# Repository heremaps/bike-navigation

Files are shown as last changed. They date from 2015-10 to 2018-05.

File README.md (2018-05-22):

# This repository has been archived!

The current version of the HERE WeGo app on Android does not support BLE devices anymore.

# BikeNavigation

The bike navigation project was born out of the HERE maker lab in Berlin. A group of employees volunteered their time to build a companion device that connects to the HERE app on Android, including an open-source toolkit to build a custom bike navigation device.

## License

Unless otherwise noted in `LICENSE` files for specific files or directories, the [LICENSE](LICENSE) in the root applies to all content in this repository.

## Directory Contents

* *arduino*: Codes implementing BikeNavigation BLE profile
* *ble_specs*: Documentation describing BikeNavigation BLE profile
* *board*: PCB Design files for BikeNavigation
* *enclosure*: 3d and acrylic cases for BikeNavigation

## Disclaimer

You are required to provide the end-user of the device with the following notice prior to use and are responsible to localize this notice according to local laws: “Focus on the traffic when using the device - your first consideration while using the device in traffic has to be safety.”

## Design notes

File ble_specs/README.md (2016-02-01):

# BikeNavigation

## BikeNavigation BLE Profile

BikeNavigation BLE profile enables GATT client to send turn-by-turn navigation instructions to BikeNavigation device.

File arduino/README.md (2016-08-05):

# BikeNavigation

## Arduino code

Runs BikeNavigation BLE profile and controls LED matrix display.

### Arduino source files

* *ble_display.ino*: Arduino sketch file. Contains code for the board initialization and main loop, including reading of incoming commands from Bluetooth controller and getting data from the compass.
* *icons.h*: Header file containing data structures and types needed for storing LED patterns for all the icons that can be shown on the LED matrix. C++ code for patterns can be generated by code generation script (see below).
* *compass.h*: Header file describing the class to be used to deal with compass.
* *compass.cpp*: Source file containing implementation of the Compass class.

### Code generation script

Python script `generate_icons_led_matrix_studio.py` can be used to convert the output of [LED Matrix Studio](http://maximumoctopus.com/electronics/builder.htm) to the C++ structures which can be used directly in code. Usage:

    ./generate_icons_led_matrix_studio.py filename varname

Where:

* *filename*: LED patterns file generated with [LED Matrix Studio](http://maximumoctopus.com/electronics/builder.htm)
* *varname*: name of variable where LED patterns will be stored in C++ code

Generated code should be added to `icons.h` file. Also command codes and function converting command code to the icon should be adapted to the new code.

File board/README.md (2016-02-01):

# BikeNavigation

## BikeNavigation PCB & schematic

The board and the schematic are designed with [CadSoft EAGLE](http://www.cadsoftusa.com/eagle-pcb-design-software/about-eagle/). To work with the files you need at least EAGLE version 6.

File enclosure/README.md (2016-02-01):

# BikeNavigation

## Enclosure

* OpenSCAD files for 3d printed case
* SVG file for acrylic case

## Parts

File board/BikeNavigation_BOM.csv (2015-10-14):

Qty | Value | Device | Package | Parts | Description | PARTNO | PROD_ID | TP_SIGNAL_NAME
49 |  | LEDCHIP-LED0603 | CHIP-LED0603 | LED1, LED2, LED3, LED4, LED5, LED6, LED7, LED8, LED9, LED10, LED11, LED12, LED13, LED14, LED15, LED16, LED17, LED18, LED19, LED20, LED21, LED22, LED23, LED24, LED25, LED26, LED27, LED28, LED29, LED30, LED31, LED32, LED33, LED34, LED35, LED36, LED37, LED38, LED39, LED40, LED41, LED42, LED44, LED45, LED46, LED47, LED48, LED49, LED50 | LED
7 |  | PNP-TRANSISTOR_SOT23 | SOT23 | Q1, Q2, Q3, Q4, Q5, Q6, Q7 | PNP TRANSISTOR
1 |  | SJ | SJ | SJ1 | SMD solder JUMPER
1 | 100K | R-EU_R0402 | R0402 | R5 | RESISTOR, European symbol
1 | 100K | R-EU_R0402 | R0402 | R15 | RESISTOR, European symbol | P100KJCT-ND
1 | 100K | R-EU_R0402 | R0402 | R9 | RESISTOR, European symbol | P510KJCT-ND
3 | 100n | C-EUC0402 | C0402 | C1, C5, C10 | CAPACITOR, European symbol | 445-3445-1-ND
1 | 10K | R-EU_R0402 | R0402 | R2 | RESISTOR, European symbol
1 | 10n | C-EUC0402 | C0402 | C11 | CAPACITOR, European symbol | 445-1260-1-ND
1 | 16Mhz | RESONATORSMD | RESONATOR-SMD | Y2 | Resonator | *
1 | 1K | R-EU_R0402 | R0402 | R1 | RESISTOR, European symbol
1 | 1u | CPOL-EUSMCA | SMC_A | C4 | POLARIZED CAPACITOR, European symbol
2 | 22 | R-EU_R0402 | R0402 | R12, R13 | RESISTOR, European symbol
2 | 220 | R-EU_R0402 | R0402 | R14, R16 | RESISTOR, European symbol
1 | 220n | C-EUC0402 | C0402 | C3 | CAPACITOR, European symbol | 445-3445-1-ND
1 | 2K | R-EU_R0402 | R0402 | R10 | RESISTOR, European symbol
2 | 330 | R-EU_R0402 | R0402 | R3, R4 | RESISTOR, European symbol
1 | 436331045822 | 436331045822 | 436331045822 | SW1 | WS-TUS-3.5x4.7 mm side push SMD Tact Switch with boss design, 4 pins
5 | 4u7 | CPOL-EUSMCA | SMC_A | C2, C7, C8, C9, C12 | POLARIZED CAPACITOR, European symbol
1 | ATMEGA32U4TQFP-44 | ATMEGA32U4TQFP-44 | TQFP44 | IC5 | Atmel 44-pin 8-bit Microcontroller with 32KBytes of ISP Flash and USB Controller
3 | FIDUCIAL | FIDUCIAL | FIDUCIAL_1MM | U$1, U$2, U$3 | For use by pick and place machines to calibrate the vision/machine, 1mm
1 | GRN | LEDCHIP-LED0603 | CHIP-LED0603 | RX | LED
1 | GRN | LEDSML0805 | SML0805 | LED51 | LED
1 | HM-11_HM-11 | HM-11_HM-11 | HM-11_HM-11 | HM11
1 | HMC5883LSMD | HMC5883LSMD | 16LPCC | IC1 | 3 Axis Digital Compass IC |  | IC-10284
1 | LTC2950CDDB-1 | LTC2950-1DFN(3X2) | DDB-8 | IC6 | LTC2950-1 Push button ON/OFF Controler LINEAR TECHNOLOGY | LTC2950IDDB-1#TRMPBFCT-ND
1 | MCP1824-3.3V (fixed) | V_REG_LDOSMD | SOT23-5 | U1 | Voltage Regulator LDO
1 | MCP73831 | MCP73831 | SOT23-5 | U2 | Miniature single cell, fully integrated Li-Ion, Li-polymer charge management controller |  | IC-09995
1 | MICRO-USB-SMD(ZX62-B-5PA) | MICRO-USB-SMD(ZX62-B-5PA) | MICRO-USB5+6P-SMD-0.65-AB | J1 | 320010005
8 | PTR1TP20SQ | PTR1TP20SQ | TP20SQ | BAT+, BAT-, TP_GND, TP_MISO, TP_MOSI, TP_RST, TP_SCK, TP_VCC | TEST PIN
1 | RED | LEDCHIP-LED0603 | CHIP-LED0603 | TX | LED
1 | RED | LEDSML0805 | SML0805 | LED43 | LED
1 | STP16CP05 | STP16CP05 | TSSOP24 | IC2

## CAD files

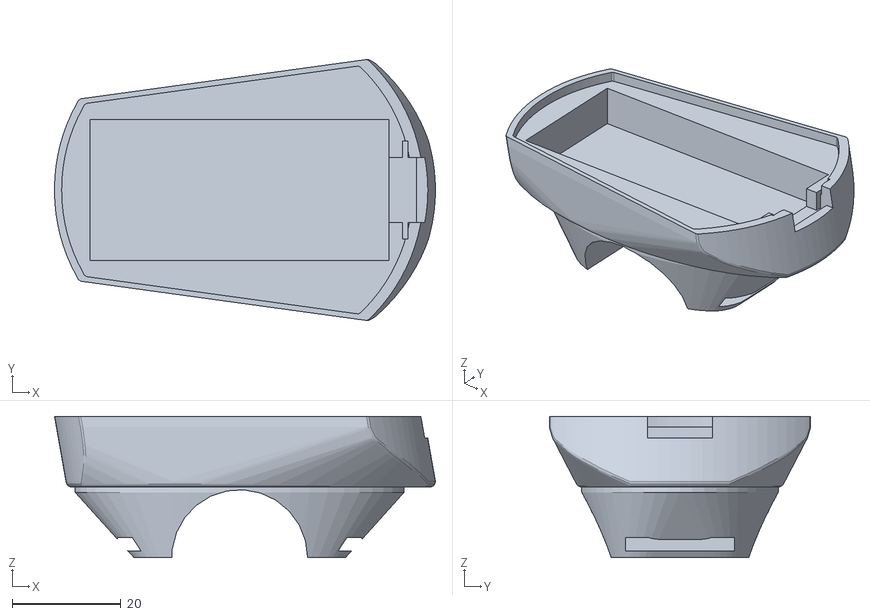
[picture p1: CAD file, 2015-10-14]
enclosure/openscad/case_B.stl
70.1 x 48.0 x 26.0

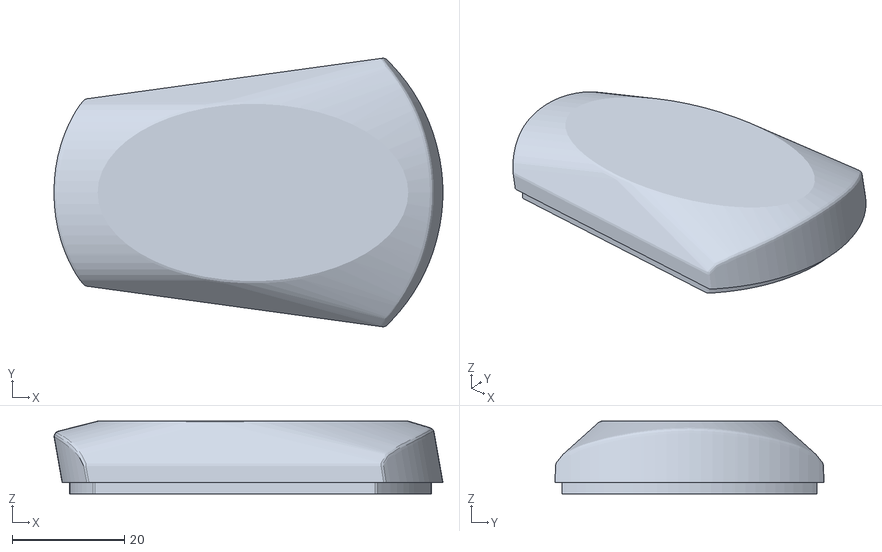
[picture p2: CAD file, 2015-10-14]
enclosure/openscad/case_A.stl
69.4 x 48.0 x 13.0

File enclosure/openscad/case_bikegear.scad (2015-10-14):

w=26;
l=55;
h=20;

module oval(w,h, height, center = false) {
 scale([1, h/w, 1]) cylinder(h=height, r=w, center=center,$fn=50);
}

module block(l,w,h){
union(){
	//display matrix 20x20x6, modify h-x to control height
	color("white")translate([20/2+11.5,0,3.2+(h-6)]) cube([20,20,6],center=true);
	//clearance pcb to display
	color("green")translate([l/2,0,(h-5)]) cube([l,w,2],center=true);
	//pcb and battery volume
	color("red") translate([l/2,0,(h-6)/2]) cube ([l,w,h-6], center=true);
}//union
}//block(l,w,h);

module body(){
intersection(){
hull(){
	oval(l*0.7,w*0.7,2,false);
	translate([0,0,10]) hull(){
		translate([-l/2,0,0])oval(l*0.5,w*0.6,5,false);
		translate([l/2,0,0]) cylinder(h=5,r=w/2*1.8, $fn=25);
	}
	translate([0,0,h]) oval(l*0.5,w*0.6,2,false);

}//hull

//make something more interesting with the front and back
rotate(a=-10,v=[0,1,0]) translate([2,0,-20]) cylinder(h=70,r=65/2,$fn=100);

}//intersect
}//translate([l/2,0,-3]) body();

module soften_body(shell=false){
difference(){
 minkowski(){
	sphere(1,$fs=0.5);
	translate([l/2,0,-2]) body();
}
	block(l,w,h);
//we empthy the mass, and leave just outer shell
if(shell==true) { translate([1,0,0.5]) scale(0.95) minkowski(){
	sphere(1,$fs=0.5);
	translate([l/2,0,-2]) body();
	}//mink
	}//if
	}//diff
}//soften_body(false);

//to test the cut seam
zcut=10;
//projection(cut=true) translate([0,0,-zcut]) soften_body(true);

//seam prep
module seam(){
difference(){
 translate([1,0,0.5]) scale(0.95) minkowski(){
	sphere(1,$fs=0.5);
	translate([l/2,0,-2]) body();
	}
 translate([1.6,0,0.5]) scale([0.92,0.9,0.9]) minkowski(){
	sphere(1,$fs=0.5);
	translate([l/2,0,-2]) body();
	}
}//diff
}


module seam_rib(){
translate([0,0,zcut-2]) 
	linear_extrude(height=2) 
		projection(cut=true) translate([0,0,-zcut]) seam();
}

 module seam_inner(){
 translate([0,0,zcut-2]) 
	linear_extrude(height=2) 
		projection(cut=true) translate([0,0,-zcut]) {  
    translate([1,0,0.5]) scale(0.95) minkowski(){
	sphere(1,$fs=0.5);
	translate([l/2,0,-2]) body();
	}
    }
 } // seam_inner();
    
//base, handlebar 25mm radius    
module basegrip(){
difference(){
hull(){
	translate([l/2,0,-3]) oval(l*0.55,w*0.7,2,false);
	translate([l/2,0,-15]) rotate(a=90,v=[1,0,0]) translate([0,0,-10]) cylinder(h=20,r=25/2+2,$fn=25);
}//hull
	translate([l/2,0,-25]) cube([40,40,20],center=true);
	handlebar();
	translate([l/2-25/2-5,0,-25/2]) cube([10,20,2.5],center=true);
	translate([l/2-25/2-3,0,-25/2-1.5]) rotate(a=60,v=[0,1,0]) cube([4,18,2.5],center=true);
	translate([l/2+25/2+5,0,-25/2]) cube([10,20,2.5],center=true);
	translate([l/2+25/2+3,0,-25/2-1.5]) rotate(a=60,v=[0,-1,0]) cube([4,18,2.5],center=true);

}//diff
}//basegrip();


module handlebar(){
	color("blue") translate([l/2,0,-15]) rotate(a=90,v=[1,0,0]) translate([0,0,-50]) cylinder(h=100,r=25/2,$fn=25);
}//handlebar();


module assy(){
union(){
	soften_body();
	translate([0,0,-1]) basegrip();
}
} //assy();


module cut_b(){ //bottom
union(){
	difference(){
		assy();
		translate([0,0,35]) cube([200,100,50],center=true);
		//%seam_rib();
        seam_inner();
		//switch space
		translate([l,0,8]) cube([24,12,4],center=true);
		translate([l,0,8]) cube([10,12,8],center=true);
		translate([l+3,0,8]) cube([1,18,8],center=true);
	}//diff
	
}//union
} 
//translate([0,0,-20])
//cut_b();

module cut_a(){ //top
union(){
    difference(){
            assy();
            //cut_b();
            translate([0,0,-15]) cube([200,100,50],center=true);
            //translate([l,0,5]) cube([12,12,8],center=true);
    }
    seam_rib();
    }//union 
} cut_a();

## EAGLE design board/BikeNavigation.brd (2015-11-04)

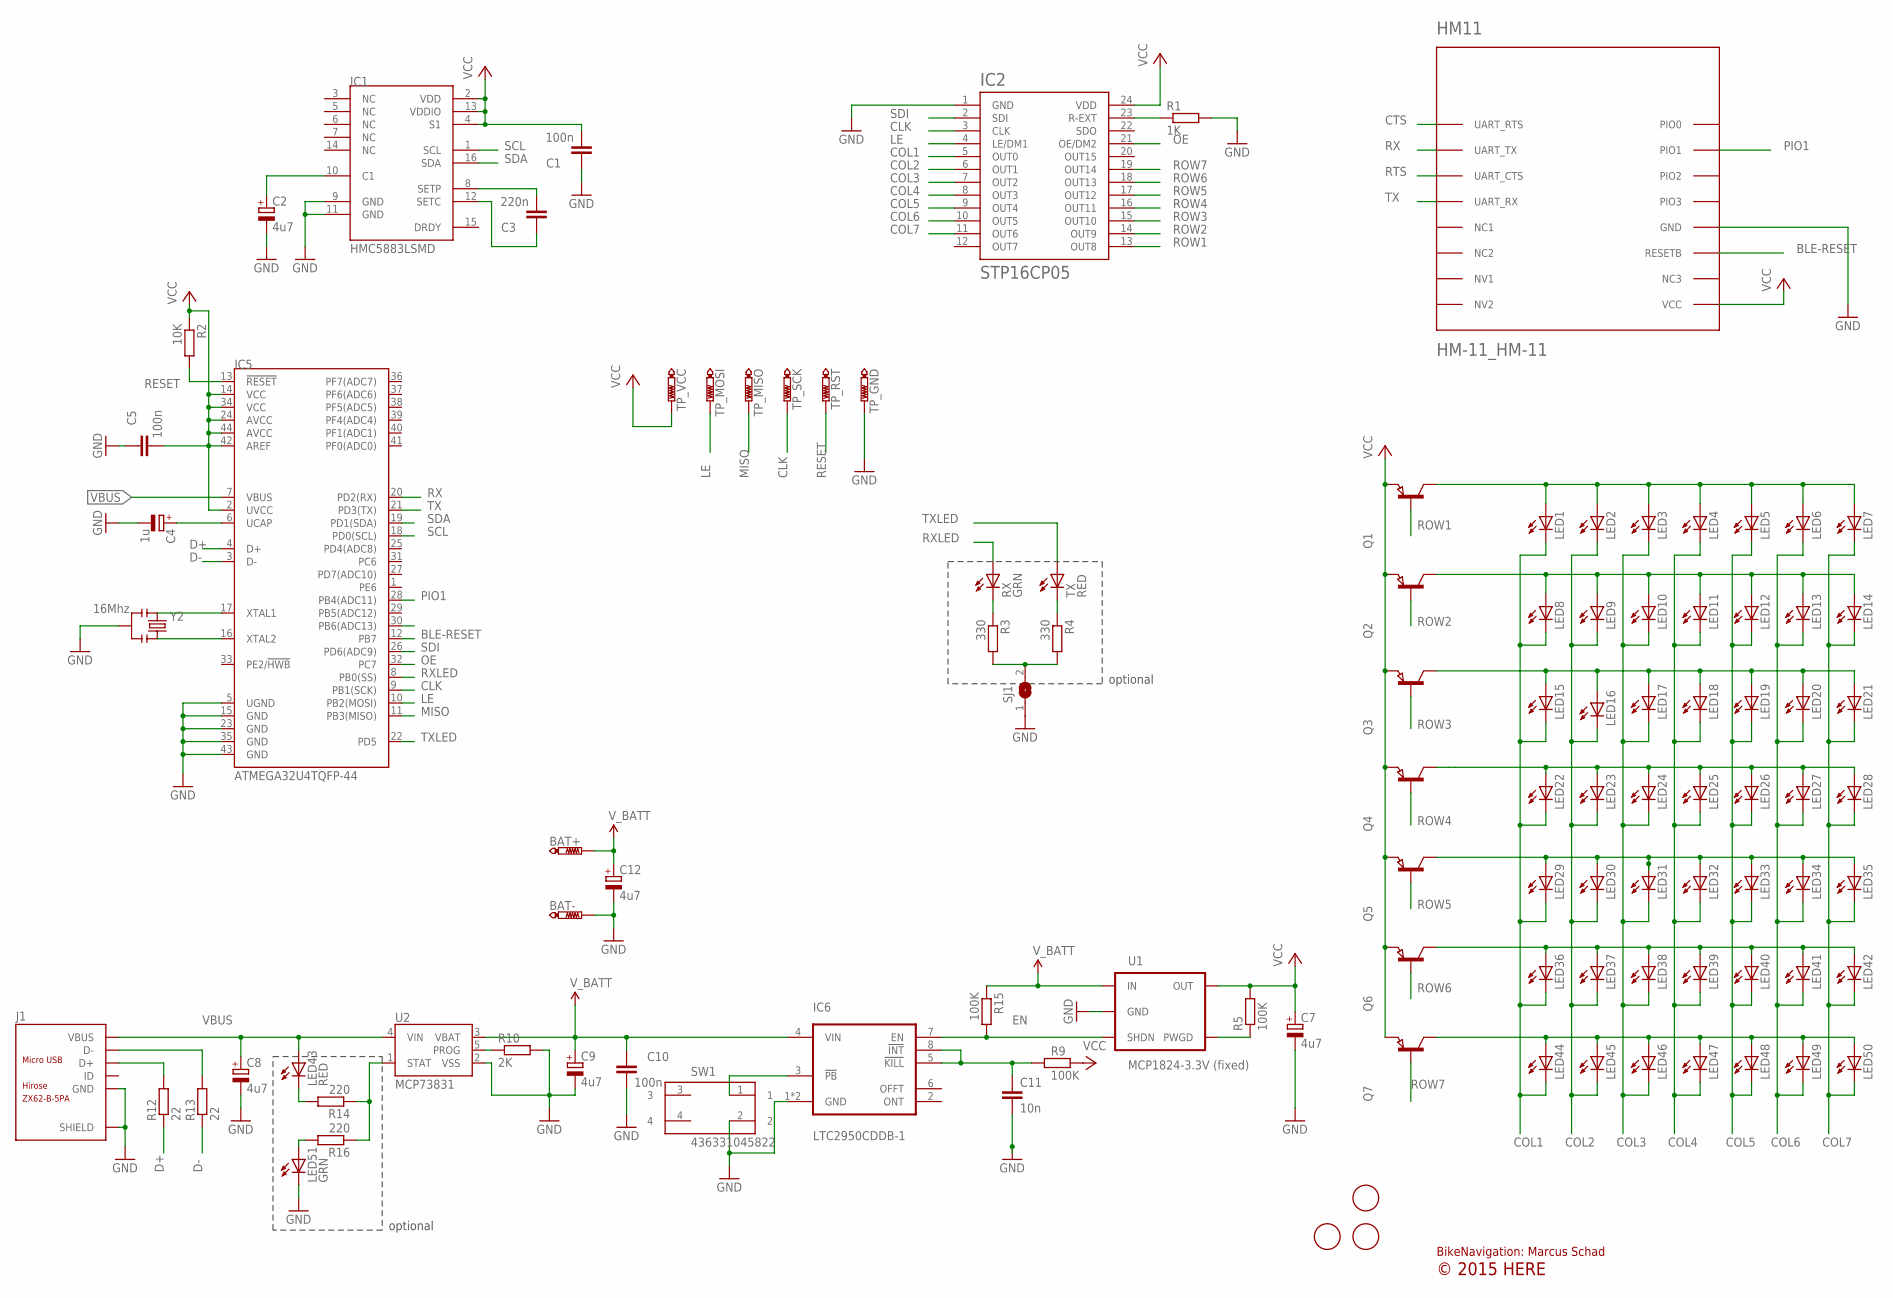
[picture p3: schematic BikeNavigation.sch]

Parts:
BAT+: PTR1TP20SQ; TP20SQ
BAT-: PTR1TP20SQ; TP20SQ
C1, C5, C10: 100n; C0402; PARTNO 445-3445-1-ND
C2, C7, C8, C9, C12: 4u7; SMC_A
C3: 220n; C0402; PARTNO 445-3445-1-ND
C4: 1u; SMC_A
C11: 10n; C0402; PARTNO 445-1260-1-ND
HM11: HM-11_HM-11
IC1: HMC5883LSMD; 16LPCC
IC2: STP16CP05; TSSOP24
IC5: ATMEGA32U4TQFP-44; TQFP44
IC6: LTC2950CDDB-1; DDB-8; PARTNO LTC2950IDDB-1#TRMPBFCT-ND
J1: MICRO-USB-SMD(ZX62-B-5PA); MICRO-USB5+6P-SMD-0.65-AB
LED1, LED2, LED3, LED4, LED5, LED6, LED7, LED8, LED9, LED10, LED11, LED12, LED13, LED14, LED15, LED16, LED17, LED18, LED19, LED20, LED21, LED22, LED23, LED24, LED25, LED26, LED27, LED28, LED29, LED30, LED31, LED32, LED33, LED34, LED35, LED36, LED37, LED38, LED39, LED40, LED41, LED42, LED44, LED45, LED46, LED47, LED48, LED49, LED50: LEDCHIP-LED0603; CHIP-LED0603
LED43: RED; SML0805
LED51: GRN; SML0805
Q1, Q2, Q3, Q4, Q5, Q6, Q7: PNP-TRANSISTOR_SOT23; SOT23
R1: 1K; R0402
R2: 10K; R0402
R3, R4: 330; R0402
R5: 100K; R0402
R9: 100K; R0402; PARTNO P510KJCT-ND
R10: 2K; R0402
R12, R13: 22; R0402
R14, R16: 220; R0402
R15: 100K; R0402; PARTNO P100KJCT-ND
RX: GRN; CHIP-LED0603
SJ1: SJ
SW1: 436331045822
TP_GND: PTR1TP20SQ; TP20SQ
TP_MISO: PTR1TP20SQ; TP20SQ
TP_MOSI: PTR1TP20SQ; TP20SQ
TP_RST: PTR1TP20SQ; TP20SQ
TP_SCK: PTR1TP20SQ; TP20SQ
TP_VCC: PTR1TP20SQ; TP20SQ
TX: RED; CHIP-LED0603
U1: MCP1824-3.3V (fixed); SOT23-5
U2: MCP73831; SOT23-5
U$1, U$2, U$3: FIDUCIAL; FIDUCIAL_1MM
Y2: 16Mhz; RESONATOR-SMD; PARTNO *

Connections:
$NS100: LED1.A, LED2.A, LED3.A, LED4.A, LED5.A, LED6.A, LED7.A, Q1.3 (C)
$NS101: LED8.A, LED9.A, LED10.A, LED11.A, LED12.A, LED13.A, LED14.A, Q2.3 (C)
$NS102: LED15.A, LED16.A, LED17.A, LED18.A, LED19.A, LED20.A, LED21.A, Q3.3 (C)
$NS104: LED22.A, LED23.A, LED24.A, LED25.A, LED26.A, LED27.A, LED28.A, Q4.3 (C)
$NS105: LED29.A, LED30.A, LED31.A, LED32.A, LED33.A, LED34.A, LED35.A, Q5.3 (C)
$NS107: LED36.A, LED37.A, LED38.A, LED39.A, LED40.A, LED41.A, LED42.A, Q6.3 (C)
$NS109: LED44.A, LED45.A, LED46.A, LED47.A, LED48.A, LED49.A, LED50.A, Q7.3 (C)
BLE-RESET: HM11.RESETB, IC5.12 (PB7)
CLK: IC2.3 (CLK), IC5.9 (PB1(SCK)), TP_SCK.TP
COL1: IC2.5 (OUT0), LED1.C, LED8.C, LED15.C, LED22.C, LED29.C, LED36.C, LED44.C
COL2: IC2.6 (OUT1), LED2.C, LED9.C, LED16.C, LED23.C, LED30.C, LED37.C, LED45.C
COL3: IC2.7 (OUT2), LED3.C, LED10.C, LED17.C, LED24.C, LED31.C, LED38.C, LED46.C
COL4: IC2.8 (OUT3), LED4.C, LED11.C, LED18.C, LED25.C, LED32.C, LED39.C, LED47.C
COL5: IC2.9 (OUT4), LED5.C, LED12.C, LED19.C, LED26.C, LED33.C, LED40.C, LED48.C
COL6: IC2.10 (OUT5), LED6.C, LED13.C, LED20.C, LED27.C, LED34.C, LED41.C, LED49.C
COL7: IC2.11 (OUT6), LED7.C, LED14.C, LED21.C, LED28.C, LED35.C, LED42.C, LED50.C
CTS: HM11.UART_RTS
D+: IC5.4 (D+), R12.1
D-: IC5.3 (D-), R13.1
EN: IC6.7 (EN), R15.2, U1.3 (SHDN)
GND: BAT-.TP, C1.1, C2.-, C4.-, C5.1, C7.-, C8.-, C9.-, C10.2, C11.2, C12.-, HM11.GND, IC1.9 (GND), IC1.11 (GND), IC2.1 (GND), IC5.5 (UGND), IC5.15 (GND), IC5.23 (GND), IC5.35 (GND), IC5.43 (GND), IC6.1 (GND), IC6.TPAD (GND), J1.5 (GND), J1.P1 (SHIELD), J1.P2 (SHIELD), J1.P3 (SHIELD), J1.P4 (SHIELD), J1.P5 (SHIELD), J1.P6 (SHIELD), LED51.C, R1.2, R10.2, SJ1.1, SW1.2, TP_GND.TP, U1.2 (GND), U2.2 (VSS), Y2.2
LE: IC2.4 (LE/DM1), IC5.10 (PB2(MOSI)), TP_MOSI.TP
MISO: IC5.11 (PB3(MISO)), TP_MISO.TP
unnamed: R5.1, U1.4 (PWGD)
unnamed: R3.1, RX.C
unnamed: R4.1, TX.C
unnamed: IC2.23 (R-EXT), R1.1
unnamed: R3.2, R4.2, SJ1.2
unnamed: C4.+, IC5.6 (UCAP)
unnamed: LED43.C, R14.2
unnamed: LED51.A, R16.2
unnamed: J1.3 (D+), R12.2
unnamed: C2.+, IC1.10 (C1)
unnamed: J1.2 (D-), R13.2
unnamed: IC6.3 (!PB), SW1.1
unnamed: C11.1, IC6.5 (!KILL), IC6.8 (!INT), R9.1
unnamed: C3.2, IC1.8 (SETP)
unnamed: C3.1, IC1.12 (SETC)
OE: IC2.21 (OE/DM2), IC5.32 (PC7)
PIO1: HM11.PIO1, IC5.28 (PB4(ADC11))
PROG: R10.1, U2.5 (PROG)
RESET: IC5.13 (!RESET), R2.2, TP_RST.TP
ROW1: IC2.13 (OUT8), Q1.1 (B)
ROW2: IC2.14 (OUT9), Q2.1 (B)
ROW3: IC2.15 (OUT10), Q3.1 (B)
ROW4: IC2.16 (OUT11), Q4.1 (B)
ROW5: IC2.17 (OUT12), Q5.1 (B)
ROW6: IC2.18 (OUT13), Q6.1 (B)
ROW7: IC2.19 (OUT14), Q7.1 (B)
RTS: HM11.UART_CTS
RX: HM11.UART_TX, IC5.20 (PD2(RX))
RXLED: IC5.8 (PB0(SS)), RX.A
SCL: IC1.1 (SCL), IC5.18 (PD0(SCL))
SDA: IC1.16 (SDA), IC5.19 (PD1(SDA))
SDI: IC2.2 (SDI), IC5.26 (PD6(ADC9))
STAT: R14.1, R16.1, U2.1 (STAT)
TX: HM11.UART_RX, IC5.21 (PD3(TX))
TXLED: IC5.22 (PD5), TX.A
VBUS: C8.+, IC5.7 (VBUS), J1.1 (VBUS), LED43.A, U2.4 (VIN)
VCC: C1.2, C5.2, C7.+, HM11.VCC, IC1.2 (VDD), IC1.4 (S1), IC1.13 (VDDIO), IC2.24 (VDD), IC5.2 (UVCC), IC5.14 (VCC), IC5.24 (AVCC), IC5.34 (VCC), IC5.42 (AREF), IC5.44 (AVCC), Q1.2 (E), Q2.2 (E), Q3.2 (E), Q4.2 (E), Q5.2 (E), Q6.2 (E), Q7.2 (E), R2.1, R5.2, R9.2, TP_VCC.TP, U1.5 (OUT)
V_BATT: BAT+.TP, C9.+, C10.1, C12.+, IC6.4 (VIN), R15.1, U1.1 (IN), U2.3 (VBAT)
XTAL1: IC5.17 (XTAL1), Y2.1
XTAL2: IC5.16 (XTAL2), Y2.3

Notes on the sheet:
BikeNavigation: Marcus Schad
optional
© 2015 HERE

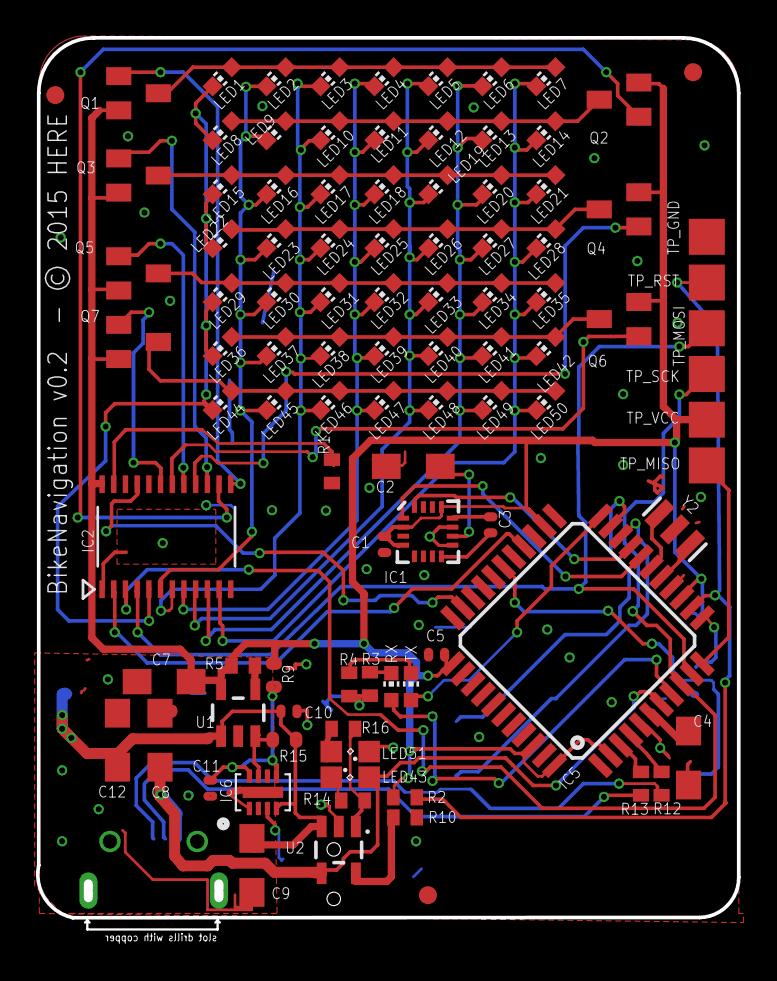
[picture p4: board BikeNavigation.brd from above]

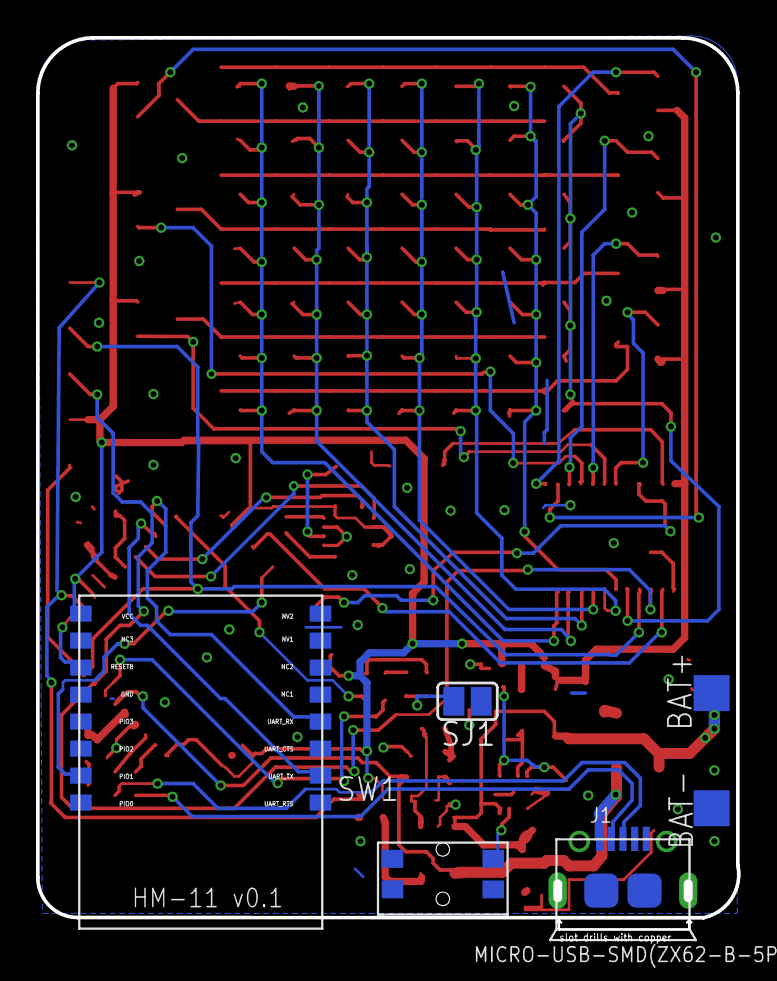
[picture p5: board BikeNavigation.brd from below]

Board: 2 copper layers, 38.9 x 49.5 mm, 105 parts (6 on the bottom side), 61 nets.

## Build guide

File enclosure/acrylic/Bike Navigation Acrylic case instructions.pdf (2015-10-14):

Bike Navi Acrylic case:

Instructions:

Use the provided SVG file, in order to construct a Bike Navi case from a 3mm Acryl board (Plexiglas). Required minimal board size is 120 mm x 240 mm.

Stack and glue 4 case walls (3 walls with a cut out on top of a wall without a cutout). Keep an eye on the cut out for USB and button, and then screw it together with the top and bottom parts. Use M2 screws 18mm or 20mm long.

For mounting the case on a bike handle, you can use a silicon elastic band.

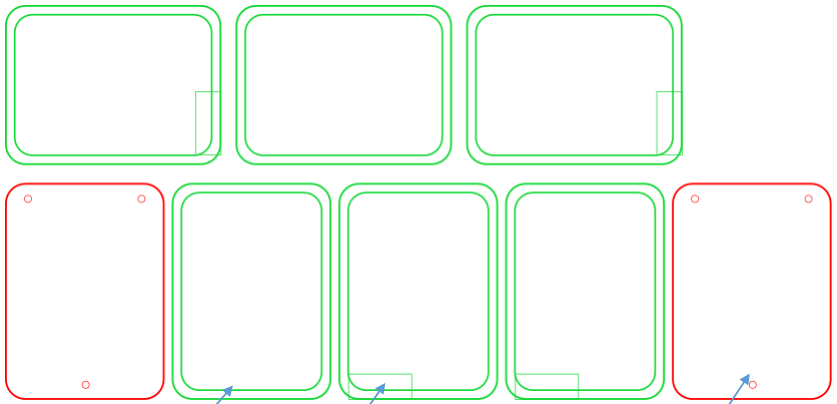
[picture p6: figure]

Wall with cutout

Wall without cutout

Top/bottom part

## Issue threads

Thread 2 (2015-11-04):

Can't open board/BikeNavigation.brd

dwlocks, 2015-11-04:
I tried uploading board/BikeNavigation.brd to oshpark.com and got  "Failed: Invalid or corrupt "brd" file".

I tried opening BikeNavigation.brd in linux 64bit eagle 7.4.0 and get this:  "Error:  line 2542, column 10: redefinition of name 'IC1' in tag <element>"

This is my first time using Eagle, so I'm afraid I didn't look any deeper than this.

eugmes, 2015-11-04:
Thanks for your report. I fixed the wrong reference, now the board can be uploaded to OSH Park. We didn't try to produce it on OSH Park, it would be interesting to know how it worked.

Closed 2015-11-04.

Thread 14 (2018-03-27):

No need to wait after Wire.requestFrom().

Koepel, 2018-03-27:
In the file "bike-navigation/arduino/ble_display/compass.cpp" the line `while (Wire.available() != count) /* wait */;` can be removed.
Explanation: [Common-mistakes#1](https://github.com/Koepel/How-to-use-the-Arduino-Wire-library/wiki/Common-mistakes#1)

Closed 2018-03-28.

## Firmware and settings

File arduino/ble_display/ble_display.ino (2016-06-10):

/*
 * Copyright (c) 2015 HERE Europe B.V.
 *
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
 * You should have received a copy of the GNU General Public License along
 * with this program; if not, write to the Free Software Foundation, Inc.,
 * 51 Franklin Street, Fifth Floor, Boston, MA 02110-1301 USA.
 */

#include <Wire.h> // Needed for compass to work

#include "icons.h"
#include "compass.h"

/* Constants needed in the board initialization */
const int LATCH_PIN = 16;
const int CLOCK_PIN = 15;
const int DATA_PIN = 12;
const int OE_PIN = 13;
const long BLUETOOTH_SERIAL_SPEED = 115200;

/* Default animation speed */
const int FRAME_DELAY = 100;

/* Sends a command to the Bluetooth controller via serial port */
static void bleSend(String s)
{
  Serial1.print(s);
  delay(100);
  processBle();
}

/* Object to work with compass */
static Compass compass;

/* Board initialization. It's called once on the startup */
void setup()
{
  pinMode(LATCH_PIN, OUTPUT);
  pinMode(CLOCK_PIN, OUTPUT);
  pinMode(DATA_PIN, OUTPUT);
  pinMode(OE_PIN, OUTPUT);
  digitalWrite(OE_PIN, LOW);

  Serial1.begin(BLUETOOTH_SERIAL_SPEED);
  delay(100);

  bleSend("AT");
  bleSend("AT+NAMEbikeN");
  bleSend("AT+UUID0xFED0");
  bleSend("AT+CHAR0xFED1");
  bleSend("AT+ROLE0");

  //Skip any junk returned by the AT commands
  delay(100);
  processBle();

  compass.setup();

}

/* Stores last read command from the Bluetooth controller */
static int command = ON;

/* Stores last shown command got from the Bluetooth controller */
static int lastShownCommand = ON;

/* Reads a byte from the Bluetooth controller via serial port */
static void processBle()
{
  while (Serial1.available()) {
    command = (byte)Serial1.read();
  }
}

/* Global variables to handle frame changes during the animation */
static int currentFrameNum = 0;
static int frameCounter = 0;
static int currentFrameDelay = FRAME_DELAY;
static bool curMirrored = false;
static const Icon * curIconPtr = &on;

/* Main loop */
void loop() {
  processBle();
  int commandToShow = command;
  if( isHeadingCommand(command))
  {
    //check the compass to get correct heading icon
    commandToShow = tuneHeadingWithCompass(command);
  }

  if(commandToShow != lastShownCommand)
  {
    bool mirrored = false;
    const Icon * iconPtr = convertCommandToIcon(commandToShow, mirrored);
    if( iconPtr != NULL )
    {
      lastShownCommand = commandToShow;
      curMirrored = mirrored;
      curIconPtr = iconPtr;

      frameCounter = 0;
      currentFrameNum = 0;
      if(curIconPtr->doubleSpeed)
      {
        currentFrameDelay = FRAME_DELAY / 2;
      }
      else
      {
        currentFrameDelay = FRAME_DELAY;
      }
    }
    else
    {
      command = lastShownCommand;
    }
  }

  if(frameCounter >= currentFrameDelay)
  {
    //switch to next frame and clear animation counter
    frameCounter = 0;
    currentFrameNum++;
    if(currentFrameNum == curIconPtr->framesNum)
    {
      currentFrameNum = 0;
    }
  }
  frameCounter++;

  showSymbol(curIconPtr, currentFrameNum, curMirrored);
}

/* Shows an icon on the matrix */
void showSymbol(const Icon * icon, int frameNum, boolean mirrored)
{
  for (int row = 0; row < MATRIX_HEIGHT; row++) {
    byte columnBitsToSend = 0;
    byte rowBitsToSend = 1 << row;

    for (int col = 0; col < MATRIX_WIDTH; col++) {
      if (icon->getRow(frameNum, row) & (1 << col)) {
        bitWrite(columnBitsToSend, mirrored? col : (6 - col), HIGH);
      }
    }

    digitalWrite(LATCH_PIN, LOW);
    shiftOut(DATA_PIN, CLOCK_PIN, MSBFIRST, rowBitsToSend);
    shiftOut(DATA_PIN, CLOCK_PIN, MSBFIRST, columnBitsToSend);
    digitalWrite(LATCH_PIN, HIGH);
  }

  digitalWrite(LATCH_PIN, LOW);
  shiftOut(DATA_PIN, CLOCK_PIN, MSBFIRST, 0);
  shiftOut(DATA_PIN, CLOCK_PIN, MSBFIRST, 0);
  digitalWrite(LATCH_PIN, HIGH);
}

/* Checks the compass data and adapts heading command to show right direction according to compass */
int tuneHeadingWithCompass(int directionCommand)
{
  //convert command to desired direction
  float dir = (directionCommand - HEADING_CODES_START) * 45;

  //add compass value
  dir += compass.getDirection();

  if(dir >= 360)
  {
    dir -= 360;
  }

  int retCommand = 0;
  if ((dir > 337.5) || (dir <= 22.5))
  {
    retCommand = HEADING_CODES_START; // 0
  }
  else if (dir <= 67.5)
  {
    retCommand = HEADING_CODES_START + 1; //45
  }
  else if (dir <= 112.5)
  {
    retCommand = HEADING_CODES_START + 2; //90
  }
  else if (dir <= 157.5)
  {
    retCommand = HEADING_CODES_START + 3; //135
  }
  else if (dir <= 202.5)
  {
    retCommand = HEADING_CODES_START + 4; //180
  }
  else if (dir <= 247.5)
  {
    retCommand = HEADING_CODES_START + 5; //225
  }
  else if (dir <= 292.5)
  {
    retCommand = HEADING_CODES_START + 6; //270
  }
  else
  {
    retCommand = HEADING_CODES_START + 7;//315
  }
  return retCommand;
}

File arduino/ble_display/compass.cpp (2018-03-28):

/*
 * Copyright (c) 2015-2018 HERE Europe B.V.
 *
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
 * You should have received a copy of the GNU General Public License along
 * with this program; if not, write to the Free Software Foundation, Inc.,
 * 51 Franklin Street, Fifth Floor, Boston, MA 02110-1301 USA.
 */

#include "compass.h"

#define COMPASS_ADDRESS 0x1E
#define COMPASS_REG_MODE 0x02
#define COMPASS_REG_DATA_OUT_X 0x03


/* Helpers */

void writeReg(byte reg, byte val)
{
  Wire.beginTransmission(COMPASS_ADDRESS);
  Wire.write(reg);
  Wire.write(val);
  Wire.endTransmission();
}

void readRegs(byte reg, int count, byte *buf)
{
  Wire.beginTransmission(COMPASS_ADDRESS);
  Wire.write(reg);
  Wire.endTransmission(false);

  Wire.requestFrom(COMPASS_ADDRESS, count);

  for (int i = 0; i < count; i++)
  {
    buf[i] = Wire.read();
  }
}

int16_t makeI16(byte msb, byte lsb)
{
  return static_cast<int16_t>(((uint16_t)msb << 8)  | lsb);
}

float correctVal(float v, float maxVal, float minVal)
{
  float range = maxVal - minVal;
  float mean = (maxVal + minVal) / 2;

  return (v - mean) / range * 2;
}

/* Compas class code */

// FIXME correction values should be saved to the EEPROM
Compass::Compass()
  : maxMeas(258.00, 228.00, 294.00)
  , minMeas(-244.00, -281.00, -210.00)
{}

CompassVec Compass::applyCalibration(const CompassVec &v) const
{
  CompassVec res(correctVal(v.x, maxMeas.x, minMeas.x),
                 correctVal(v.y, maxMeas.y, minMeas.y),
                 correctVal(v.z, maxMeas.z, minMeas.z));
  return res;
}

void Compass::setup()
{
  Wire.begin();
  delay(100);
  /* Set the continuous measurement mode. */
  writeReg(0, 0x70);
  writeReg(1, 0xA0);
  writeReg(2, 0);
}

CompassVec Compass::getMeasurements()
{
  byte buf[6];

  //writeReg(2, 1);
  //delay(10);

  readRegs(COMPASS_REG_DATA_OUT_X, 6, buf);

  float x, y, z;
  x = (float)makeI16(buf[0], buf[1]);
  z = (float)makeI16(buf[2], buf[3]);
  y = (float)makeI16(buf[4], buf[5]);

  CompassVec v(x, y, z);
  return applyCalibration(v);
}

float Compass::getDirection()
{
  CompassVec v = getMeasurements();

  //TODO try to understand why compass measuress mirrored angle (-x coordinate compensates it)
  float res = atan2(v.y, -v.x) * 180 / M_PI;
  if (res < 0)
  {
    return res + 360;
  }
  return res;
}

void Compass::doCalibration() {
  //This method makes no sense without serial output
  while(!Serial.available());
  for (;;)
  {
    CompassVec v = getMeasurements();
    maxMeas = maxMeas.maxVec(v);
    minMeas = minMeas.minVec(v);

    maxMeas.print();
    Serial.print("    ");
    minMeas.print();
    Serial.println("");
  }
}

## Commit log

2015-10-28 Arduino code: mirroring of icons was added to save RAM. Only right-sided icons are stored, left-side are shown by mirroring right-side icons.
2015-11-04 Fix the LED driver IC designation in the board file
    Change it to correct "IC2" instead of incorrect and
    duplicate "IC1". Thanks to @dwlocks for reporting.
    Closes: #2
    [BikeNavigation.brd]
2015-11-08 Added usage statement to the script generating c++ code from Led Matrix Studio output; Renamed the script generating c++ code from Led Matrix Studio output; Added some comments to the Arduino code; A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
2015-11-08 Added current set of LED patterns
2015-11-19 Remove serial monitor #define
    Move C++ code inside a folder matching the Arduino sketch name. The IDE is
    picky about this.
2018-03-28 removed waiting after Wire.requestFrom(). fixes #14
    [compass.cpp]

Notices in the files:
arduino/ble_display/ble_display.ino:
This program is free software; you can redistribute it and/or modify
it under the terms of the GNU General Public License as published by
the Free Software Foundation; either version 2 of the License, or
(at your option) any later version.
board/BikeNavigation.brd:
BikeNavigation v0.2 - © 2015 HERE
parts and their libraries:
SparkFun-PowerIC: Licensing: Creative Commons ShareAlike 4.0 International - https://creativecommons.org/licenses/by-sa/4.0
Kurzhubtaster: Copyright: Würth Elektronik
